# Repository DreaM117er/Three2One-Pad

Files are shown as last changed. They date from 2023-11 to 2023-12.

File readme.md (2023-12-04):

# Three2One Pad

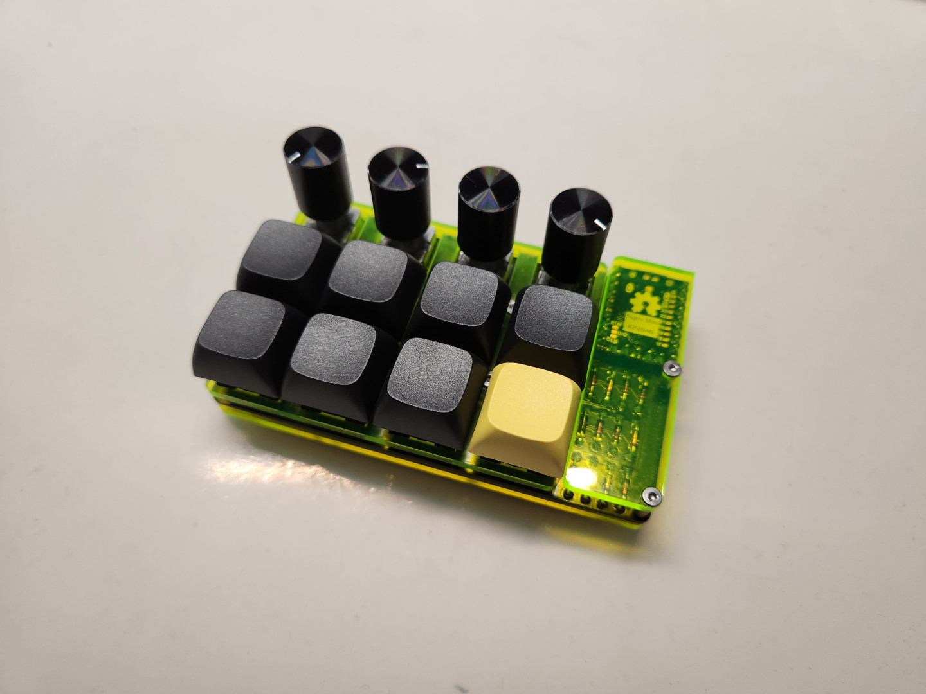
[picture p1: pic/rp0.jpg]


## Description

### What is 321 Pad?

Three2One Pad is a small keyboard pad for persional function keys. It supported maxium 12 keyboard keys or 8 keyboard keys + 4 rotray encoder, MX switches hotswap, and used RP2040 mini series micro controller (ex. supermini/zero... etc) to drive.

This is a simple repostiory, it would be opensource all files on here, check files inside floder.

### Layout and Keymap

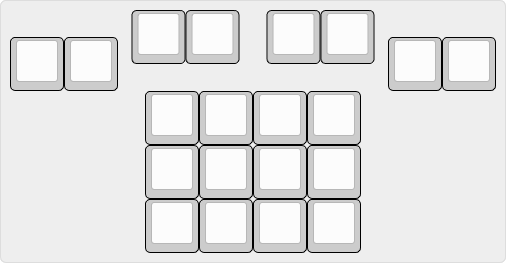
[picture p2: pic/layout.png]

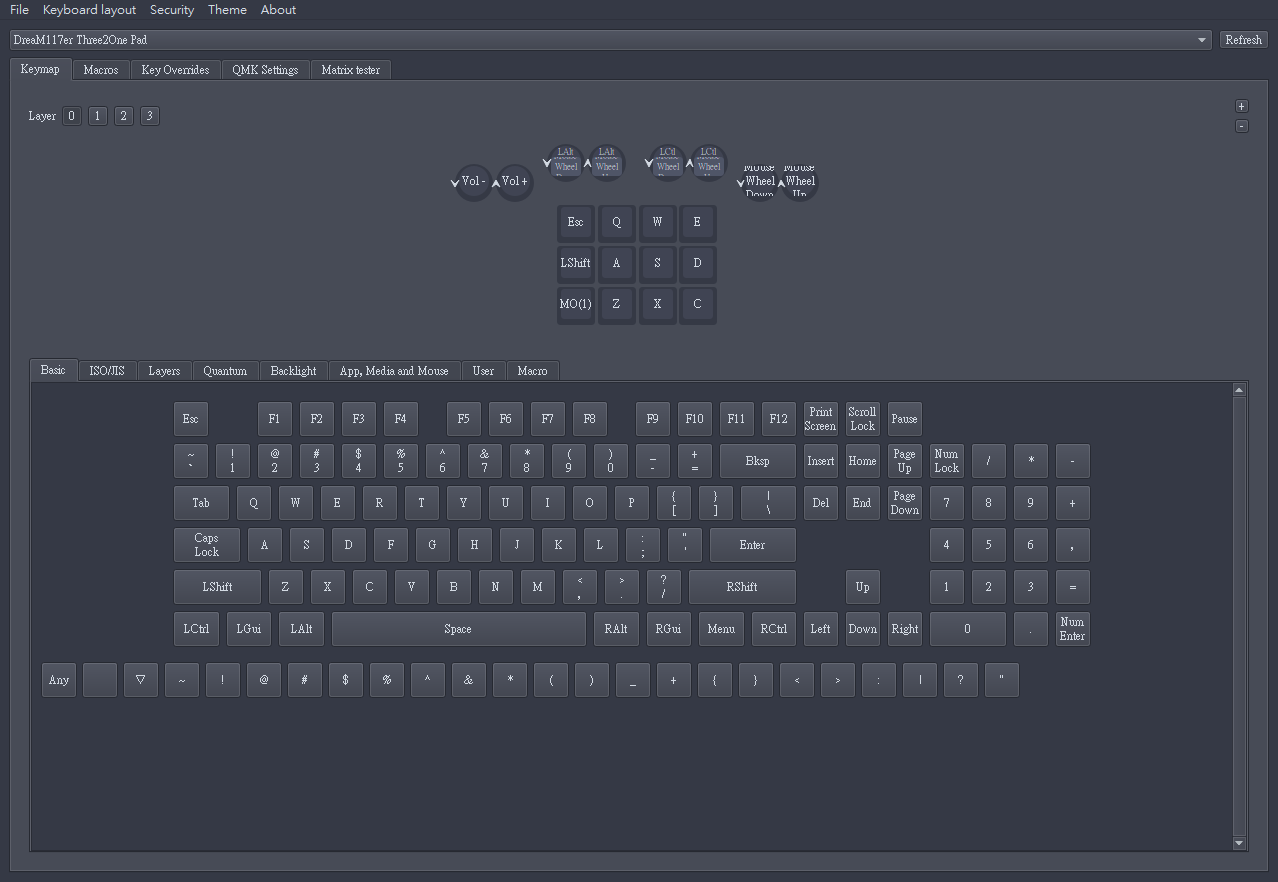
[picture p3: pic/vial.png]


## PCB & 3D module

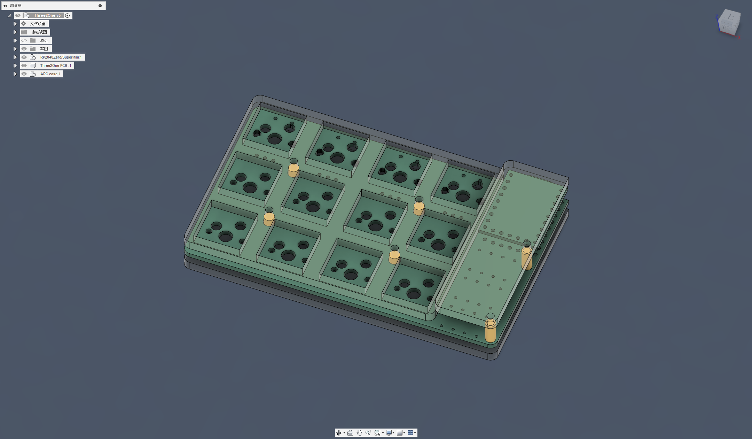
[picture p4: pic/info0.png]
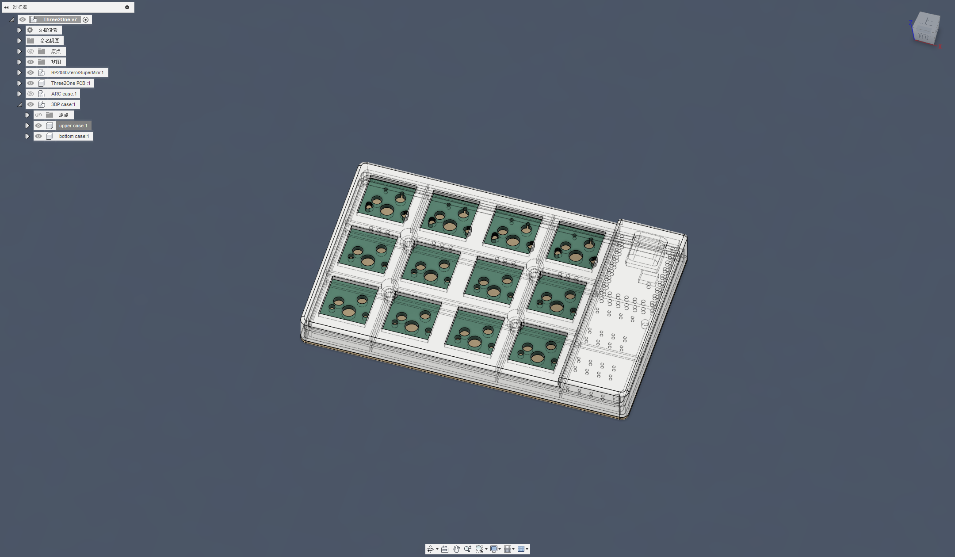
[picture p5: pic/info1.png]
|||
|---|---|
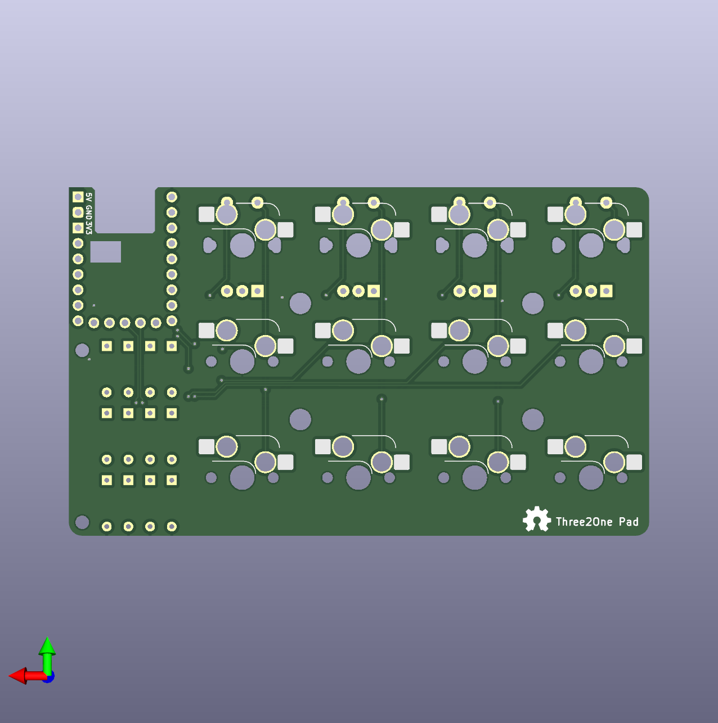
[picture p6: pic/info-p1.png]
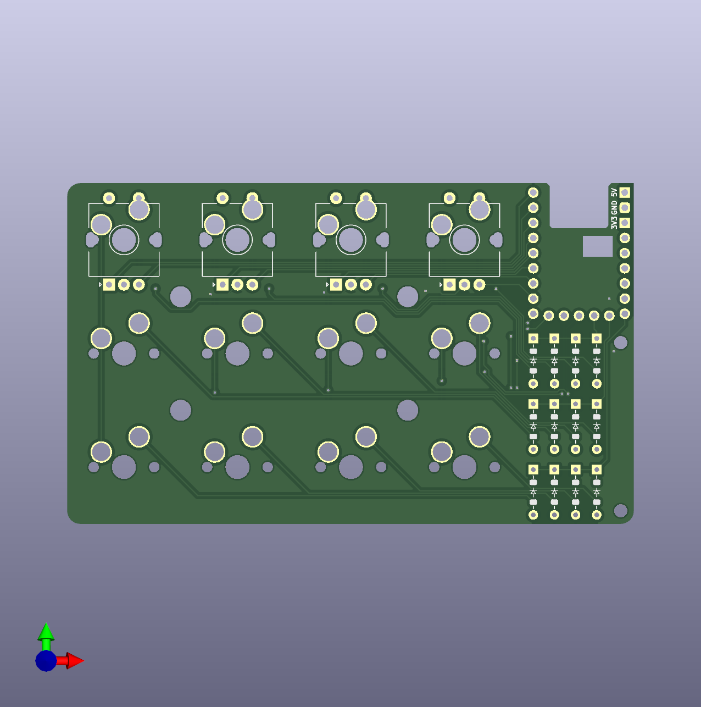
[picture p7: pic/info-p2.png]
|||

## Building Guide

### Material

|Item|Amount|Note|
|---|---|---|
|PCB|1|-|
|MCU|1|RP2040 `SuperMini`/`Zero`|
|Cases|1|`Acrylic` or `3DP`|
|Hotswap Socket|8-12|`MX` version|
|Diodes `1N4148`|12|`SOD-123` or `DO-35` version|
|`M2x5mm` Screw|12|for `Arcylic case`|
|`M2x6mm` Spacer|6|for `Arcylic case`|
|Rotray Encoder `EC-11`|0-4|`Personal Option`|
|Rubber feets|4|`ø8mm`, `H1mm`|

### Guide.1: PCB part

- Prepare hotswap sockets and solder gun, you need to install them first.

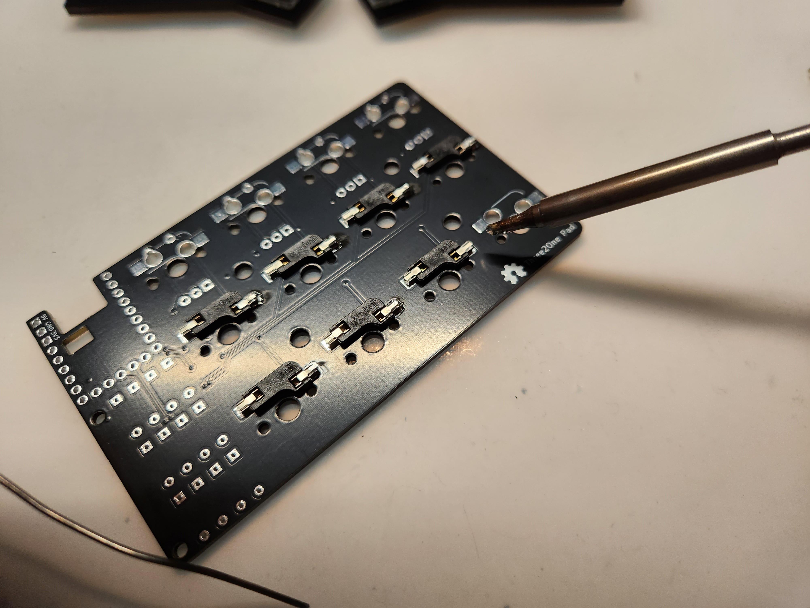
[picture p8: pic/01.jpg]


- Then install diodes to PCB.

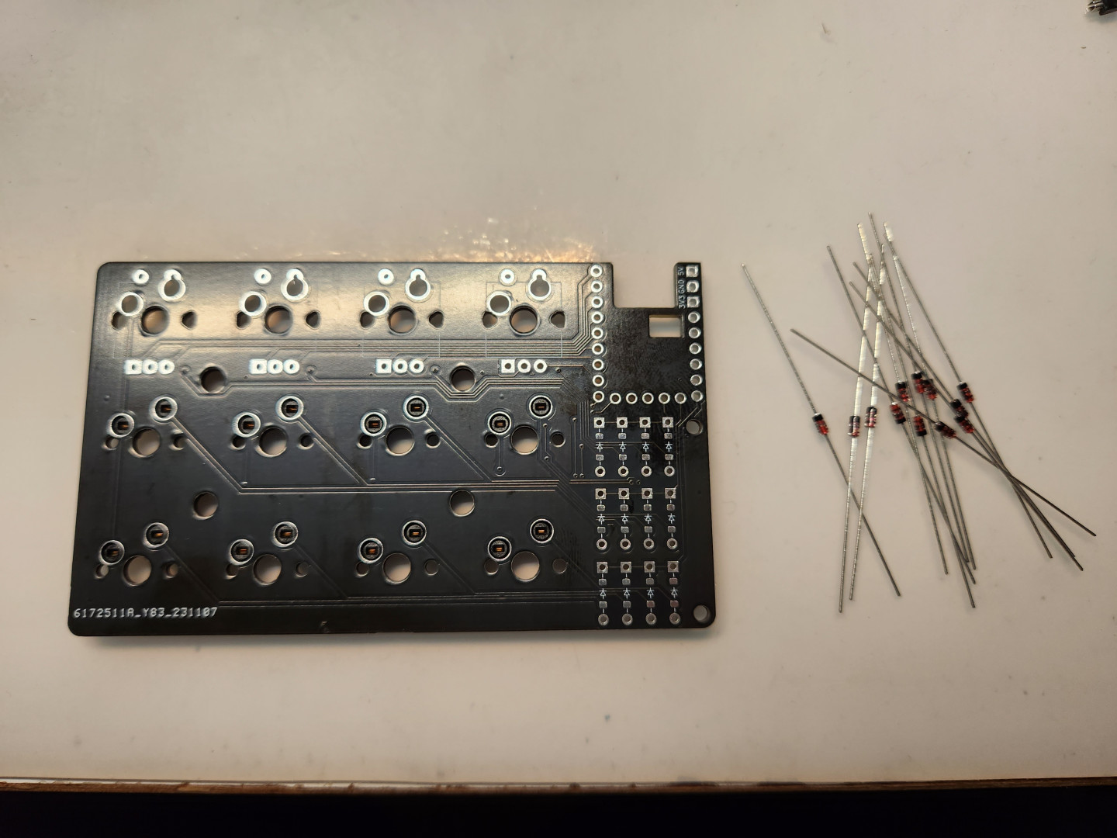
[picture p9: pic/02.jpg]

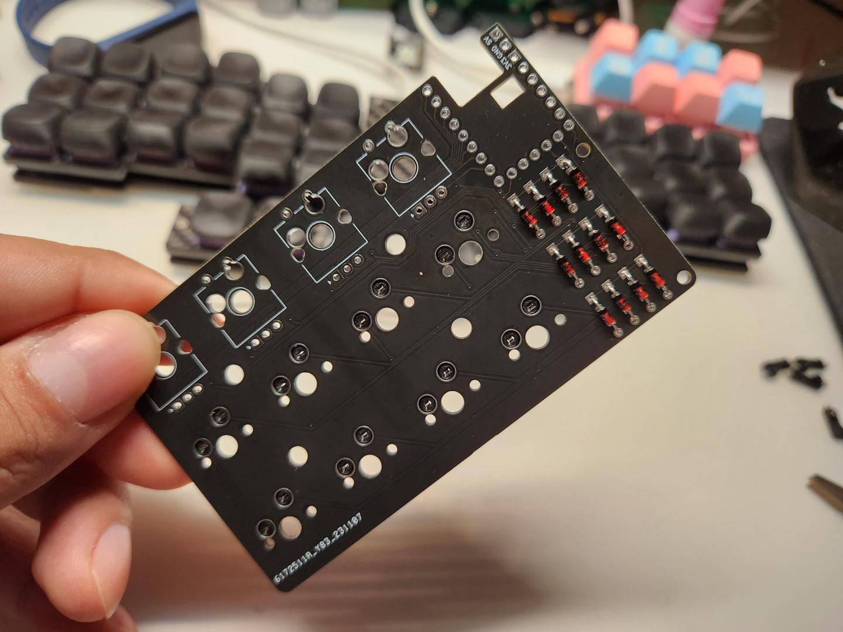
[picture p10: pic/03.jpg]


- Cut off useless diode feets after solder 1N4148 diodes.

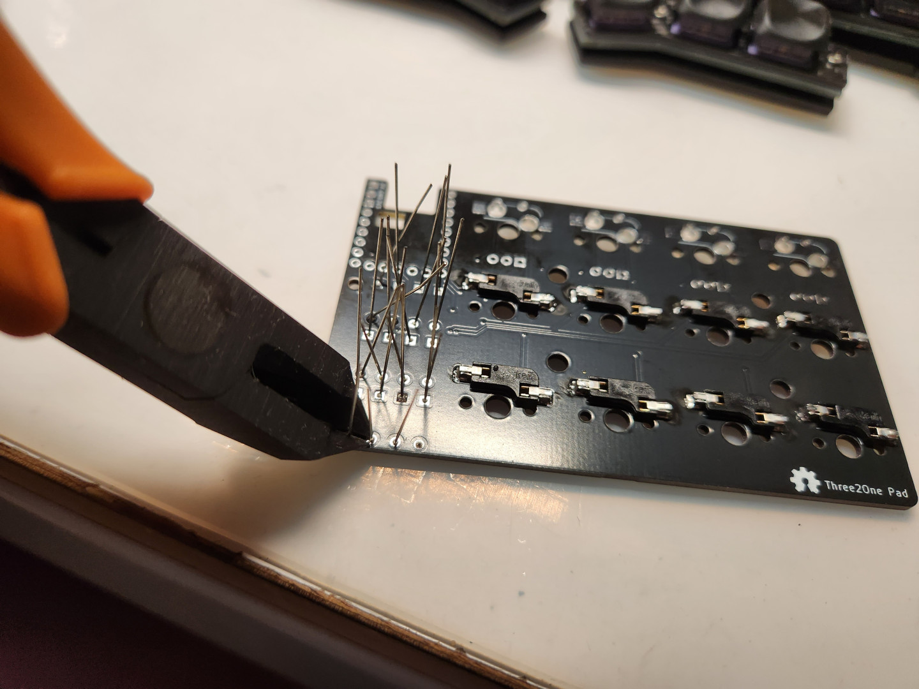
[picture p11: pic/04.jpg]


- If you finished solder diodes, next way is install MCU.

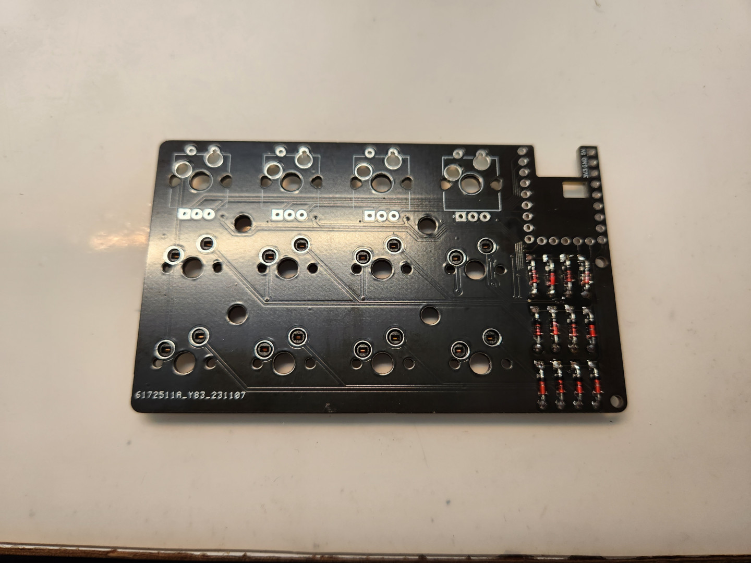
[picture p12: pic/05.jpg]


- Install pin header to PCB then put MCU on top of headers.

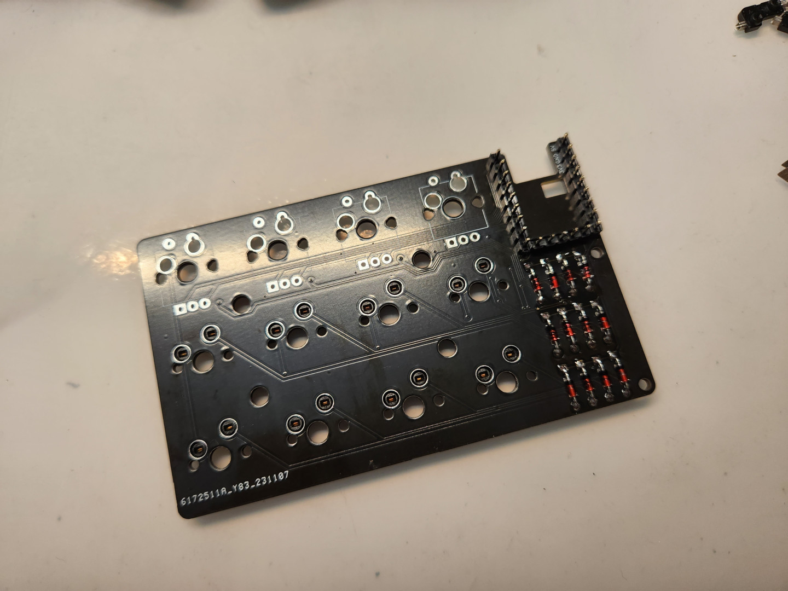
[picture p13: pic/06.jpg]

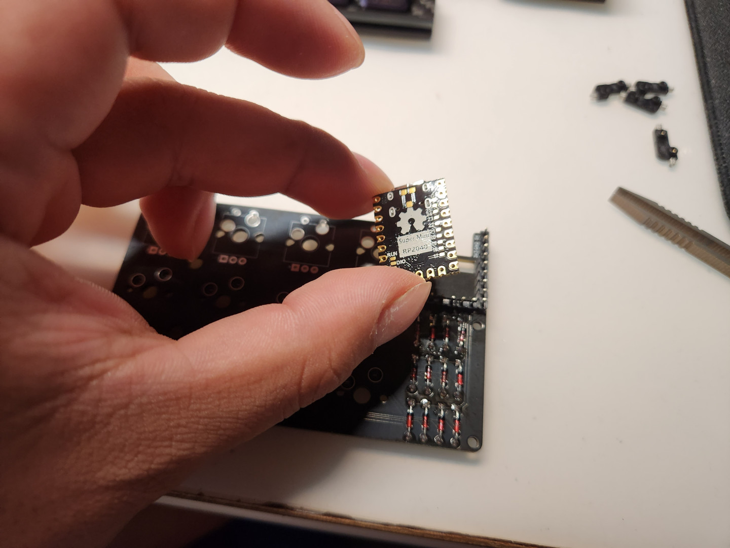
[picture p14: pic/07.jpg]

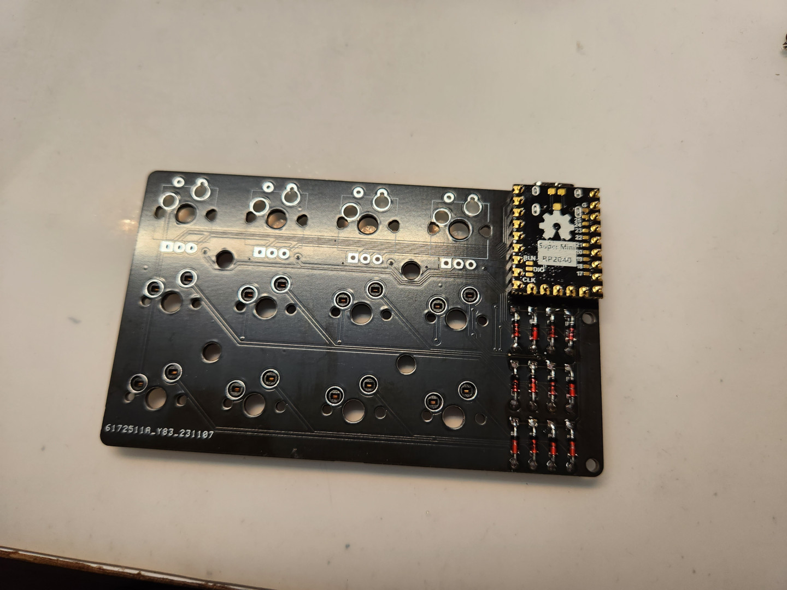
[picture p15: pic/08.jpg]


- Rotray Encoders are persional option. If you want to install them, please decide to install 0-4 EC-11(s) on the PCB.

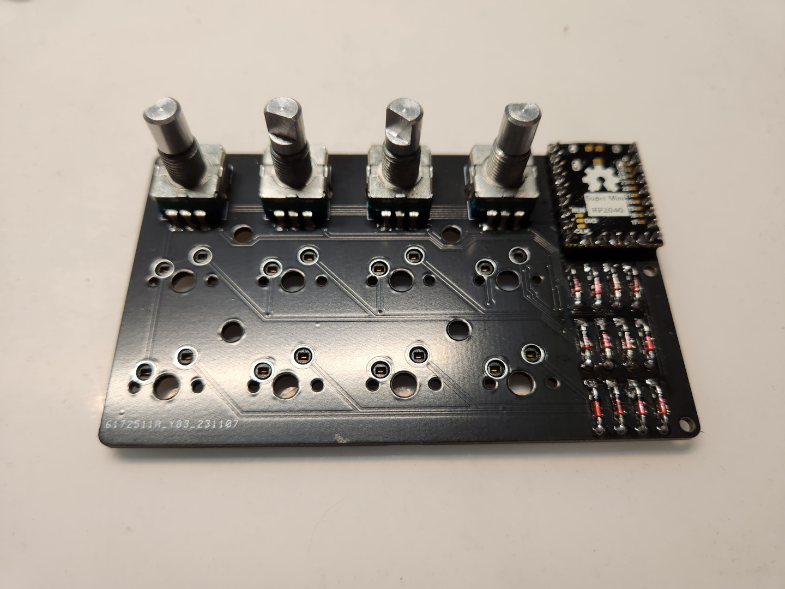
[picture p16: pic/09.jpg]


- Last step flash firmware and test how's the pad working.

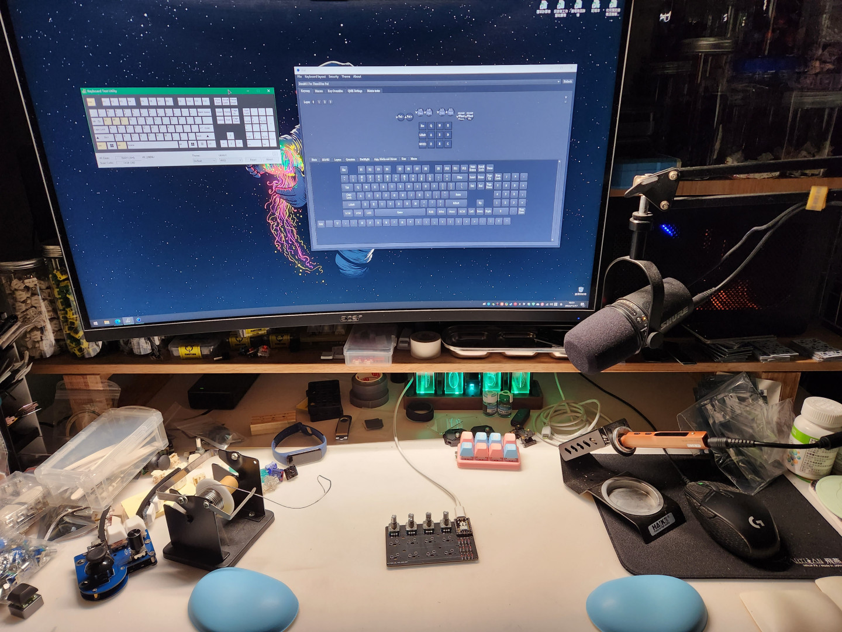
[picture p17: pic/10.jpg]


> **Note**
>
> RP2040 SuperMini/Zero have same `bootloader` way, you need to keep pushing switch on the MCU `before` plug USB-C cable to the PC. After that, you can see a `disk` on your device, then put `.uf2` firmware file into disk.

### Guide.2: Case part

- First install spacers on PCB and bottom case.

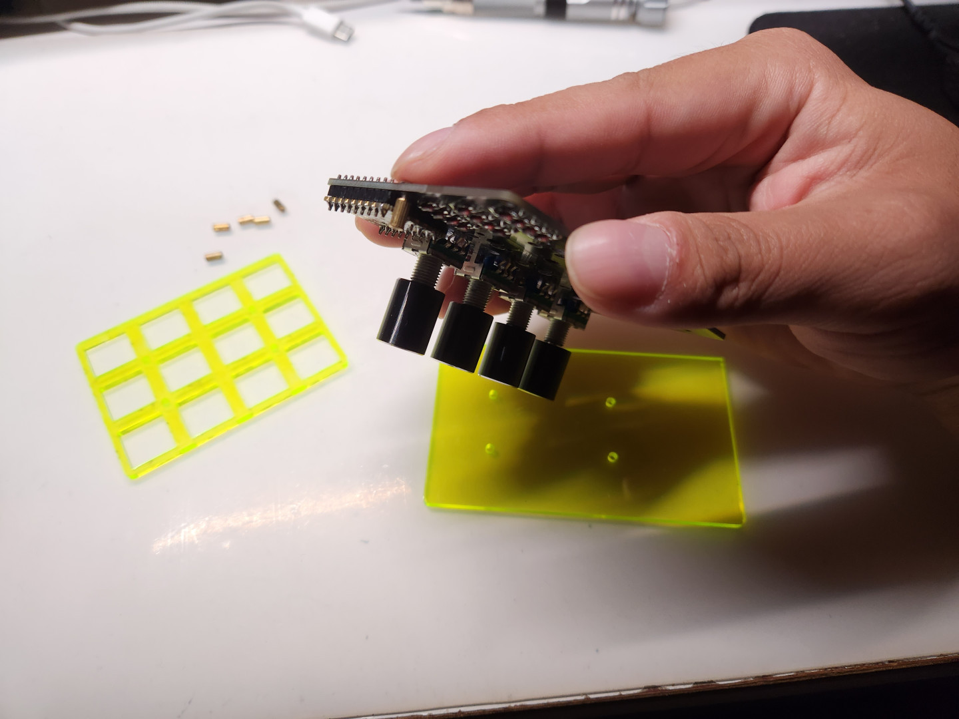
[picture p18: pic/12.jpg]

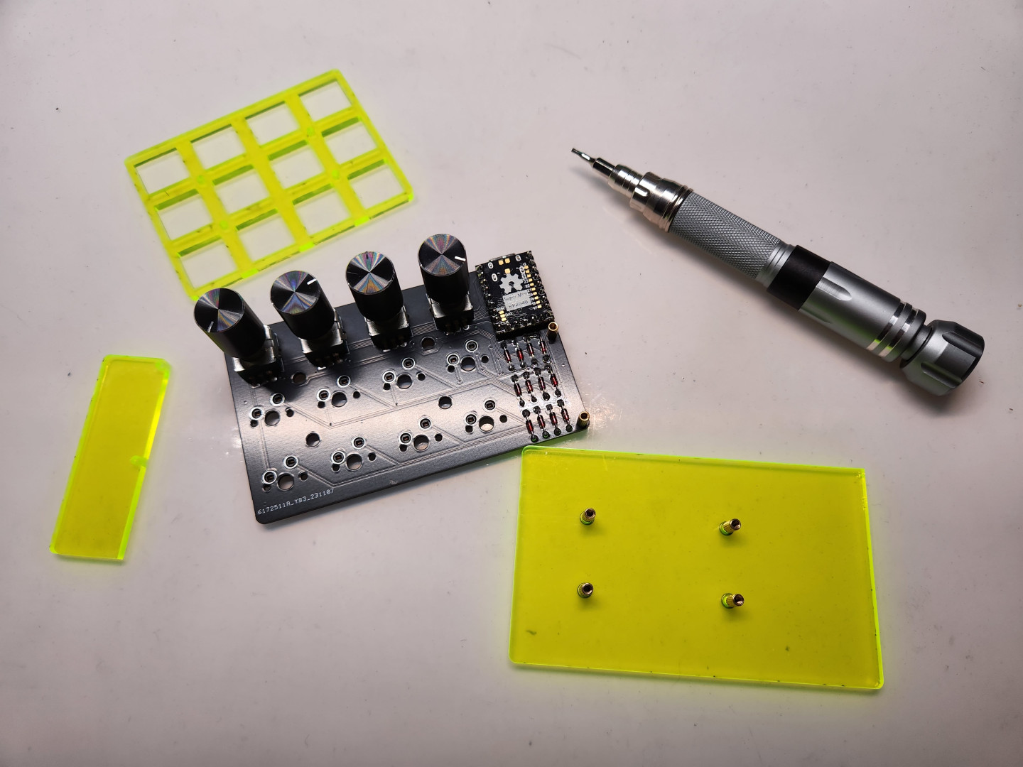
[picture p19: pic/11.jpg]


- Put the PCB on bottom case, then install plate and cover.

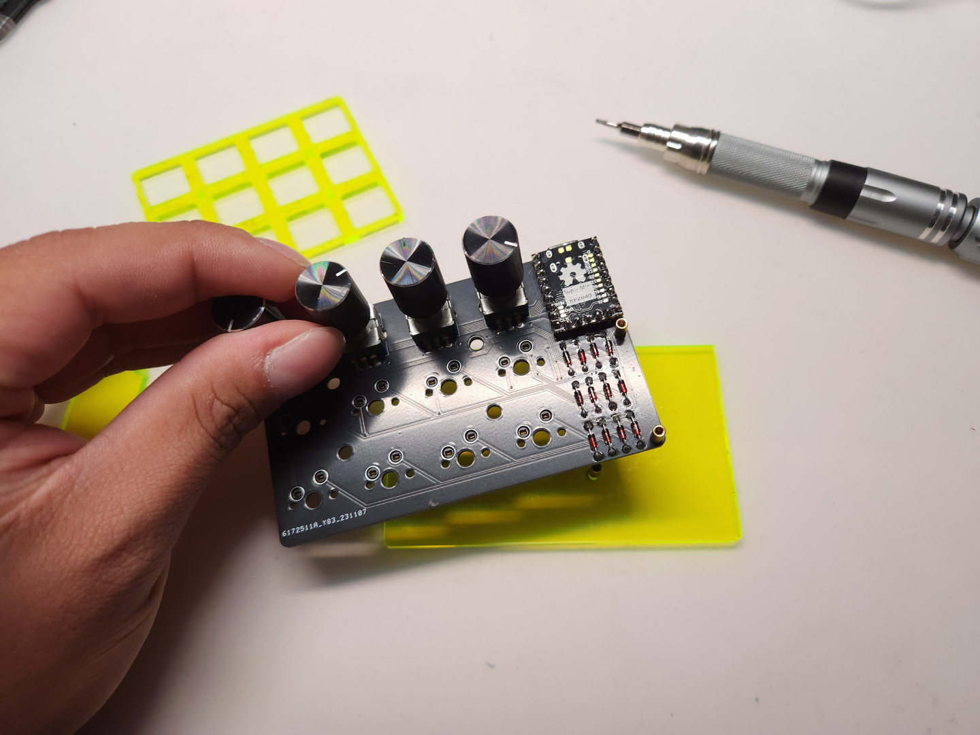
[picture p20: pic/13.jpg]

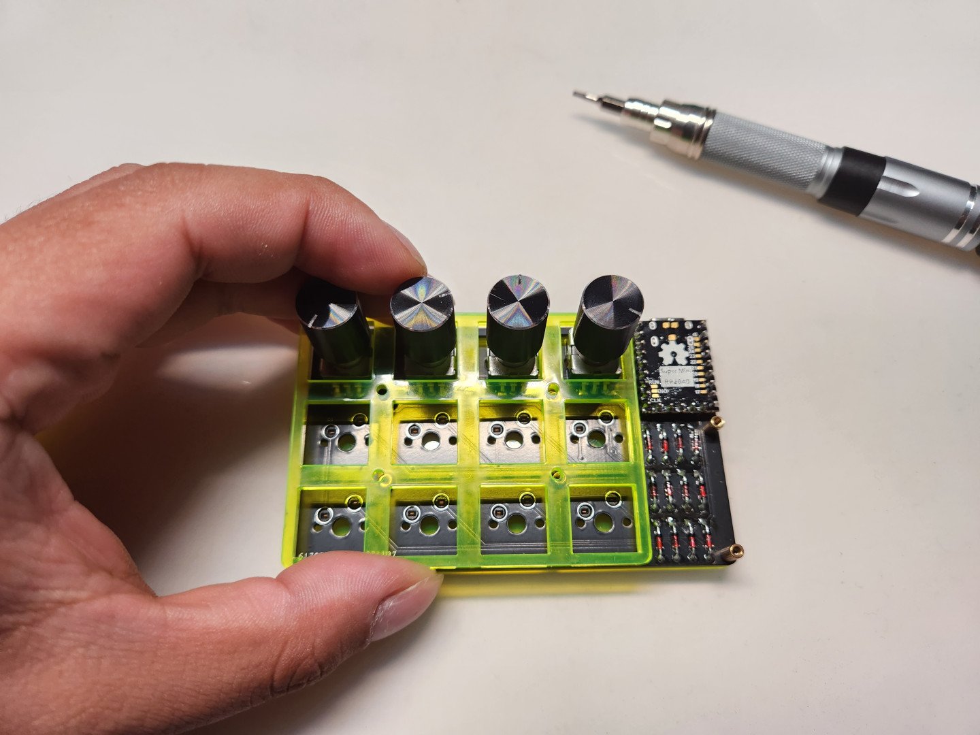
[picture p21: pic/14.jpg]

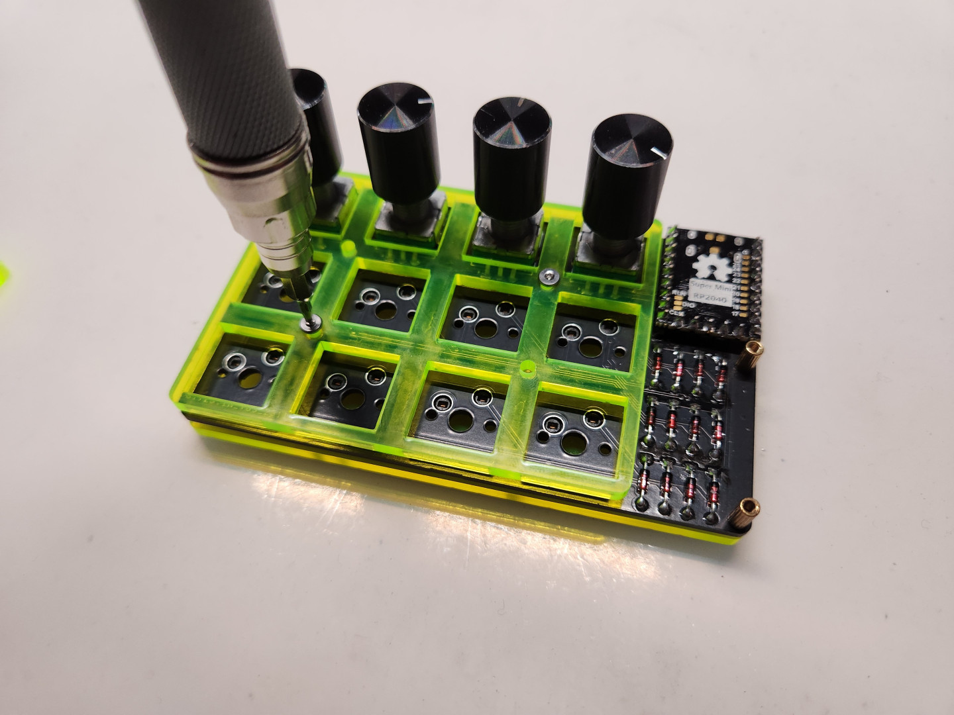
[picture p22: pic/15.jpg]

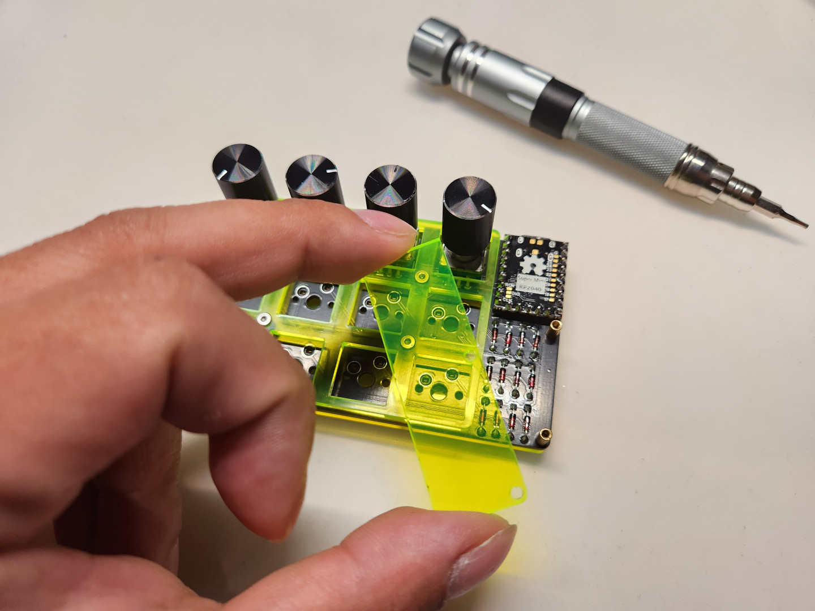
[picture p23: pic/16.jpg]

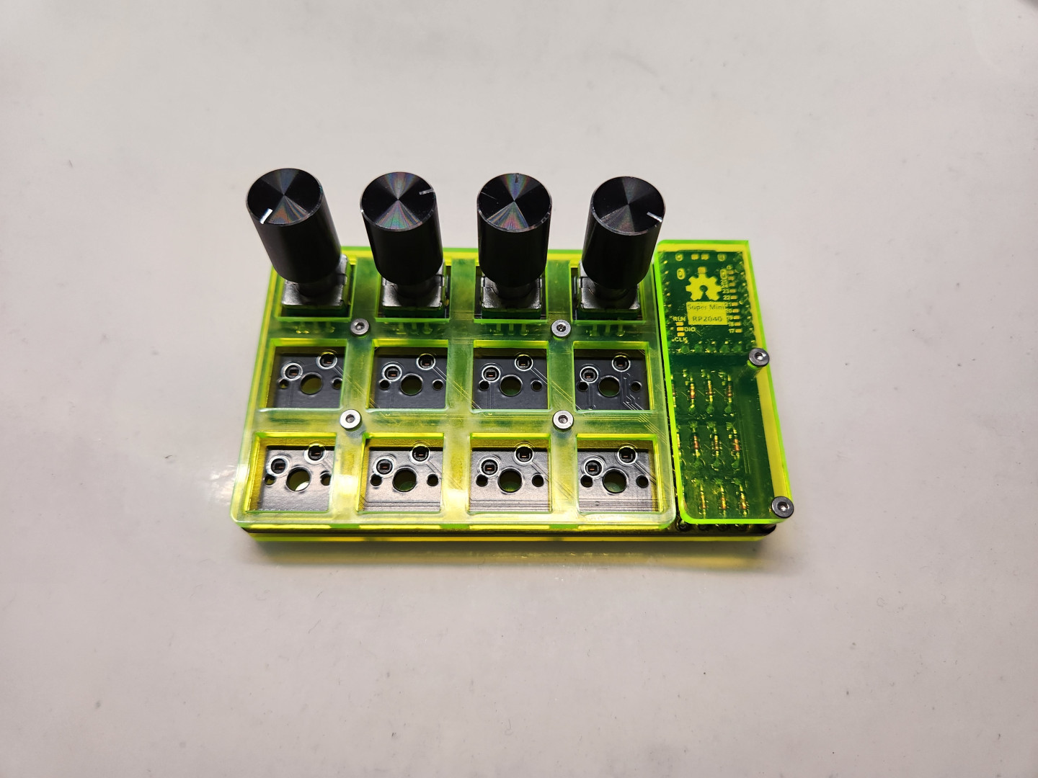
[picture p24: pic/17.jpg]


- If you finish case installed, put 4 rubber feets below the bottom case.

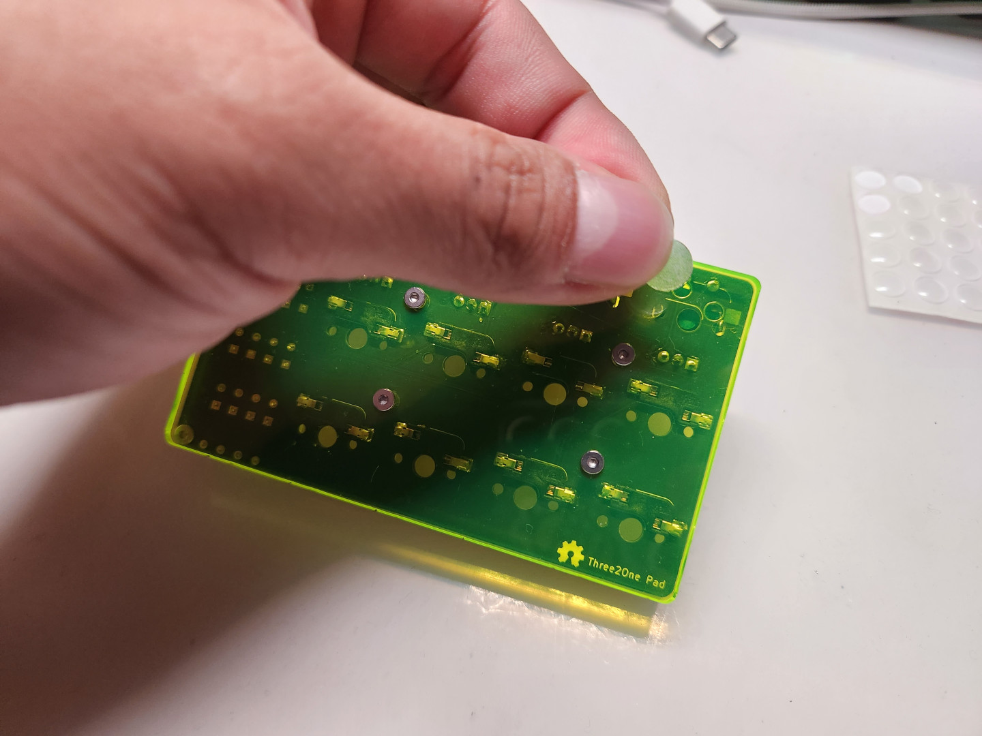
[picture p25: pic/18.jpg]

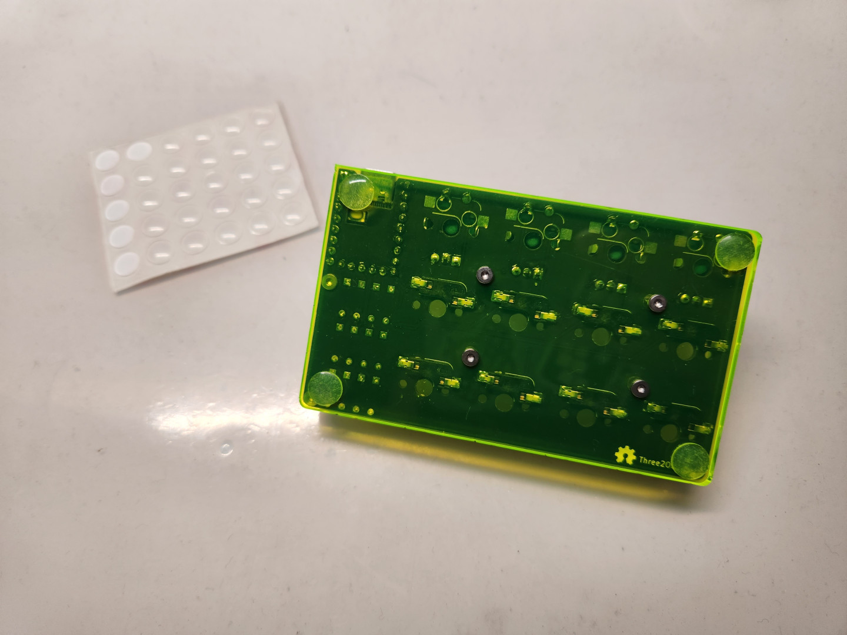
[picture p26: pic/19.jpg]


- Last step, put MX switches and keycaps on the pad.

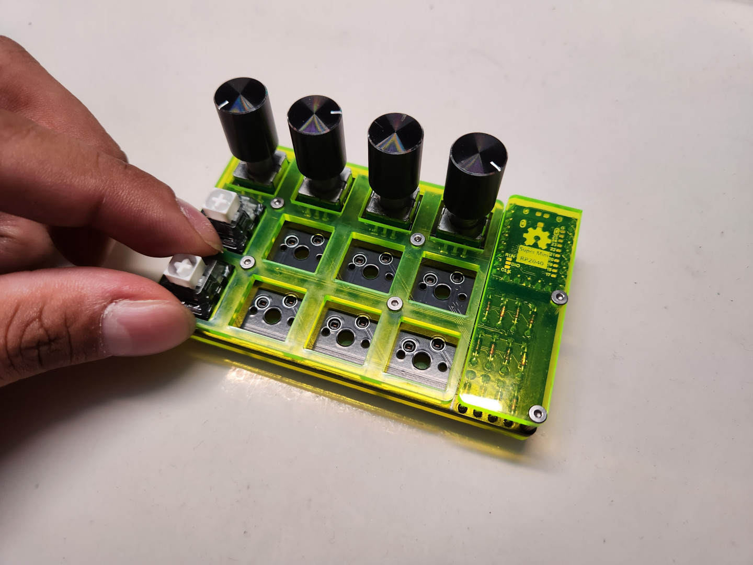
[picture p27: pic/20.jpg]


- Done.



## Informations and Special Thanks

- [QMK Firmware](https://qmk.fm/).
- [VIAL](https://get.vial.today/).
- [KiCAD](https://www.kicad.org/) version `7.0.5.`
- [JLCPCB](https://jlcpcb.com/).
- [AutoDesk Fusion360](https://www.autodesk.com/products/fusion-360/free-trial).
- Taiwan [Tatung University](https://www.ttu.edu.tw/) - [Department of Mechanical and Materials Engineering](https://mme.ttu.edu.tw/)
- And my friend: [YCT](https://github.com/yct38)

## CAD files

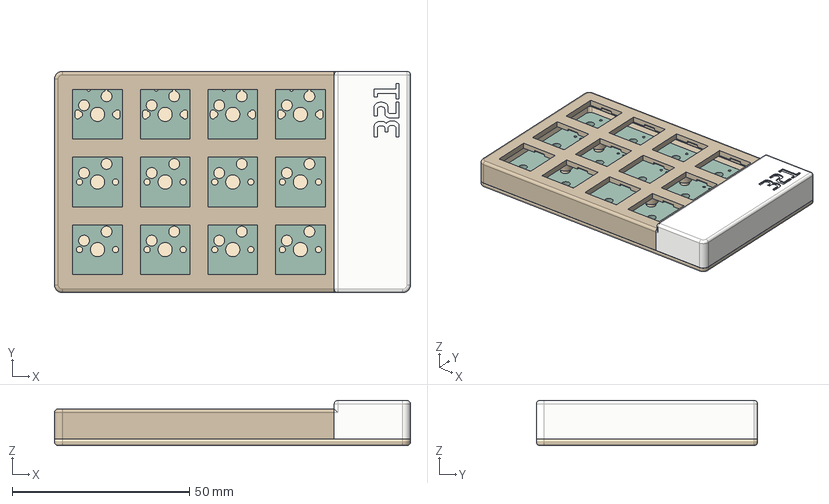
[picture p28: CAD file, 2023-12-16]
file/3Dmodule/3DP version.step
100.3 x 62.3 x 12.7 mm
MCU
Three2One PCB
upper case
bottom case
plate case

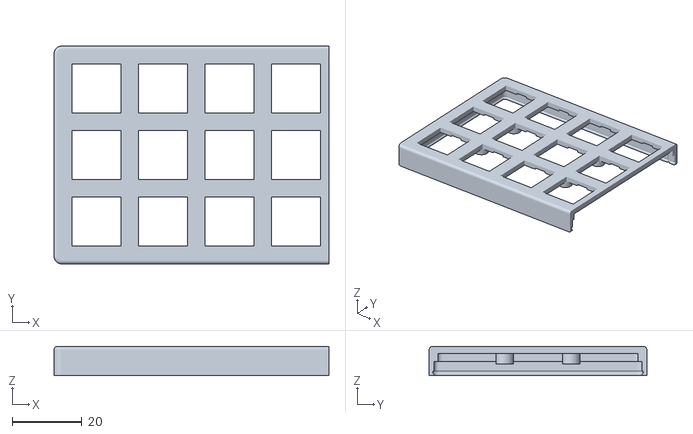
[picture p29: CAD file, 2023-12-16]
file/case/3DP/plate case.stl
78.7 x 62.3 x 8.40

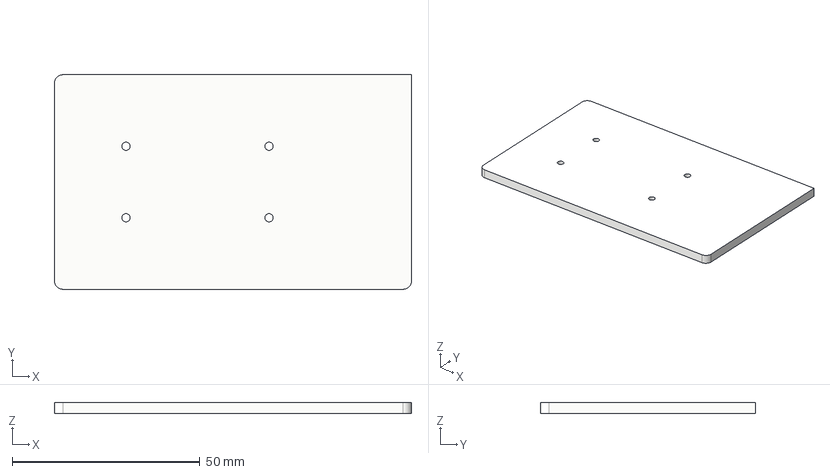
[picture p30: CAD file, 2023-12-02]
file/case/ARC/Bottom.step
95.1 x 57.1 x 3.00 mm

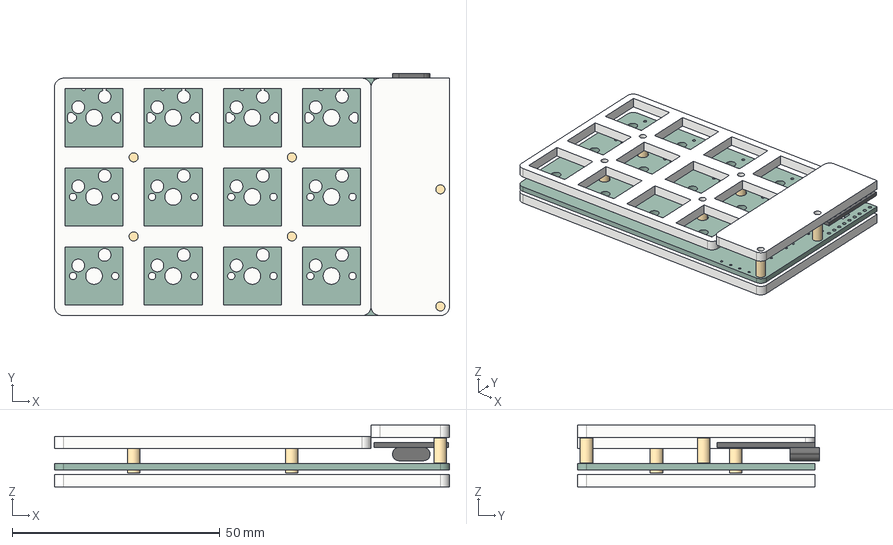
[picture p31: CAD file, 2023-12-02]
file/3Dmodule/ARC version.step
95.1 x 58.3 x 14.9 mm
MCU
Three2One PCB
Plate
Cover
Bottom
6mm spacer mcu x 2
6mm spacer x 4

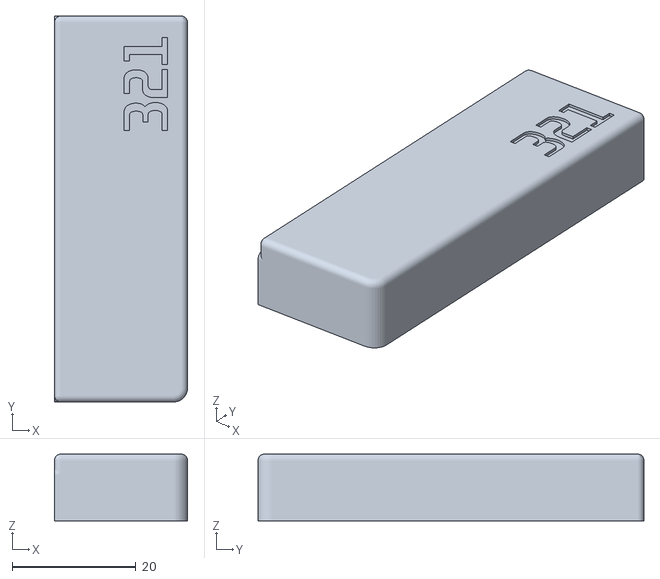
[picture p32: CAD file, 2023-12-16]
file/case/3DP/upper case.stl
21.5 x 62.3 x 10.8

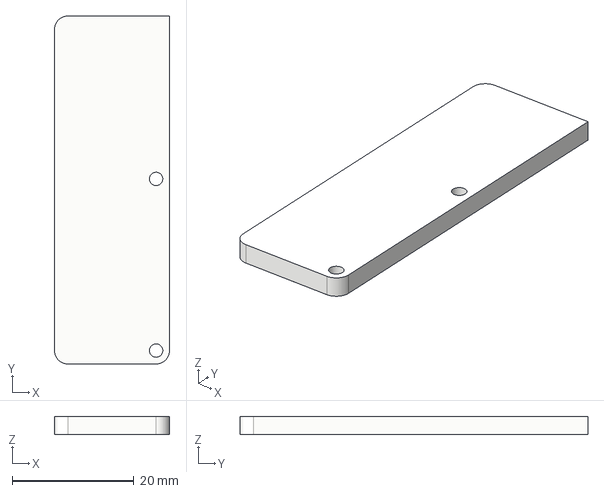
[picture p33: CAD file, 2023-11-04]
file/case/ARC/Cover.step
18.9 x 57.1 x 3.00 mm

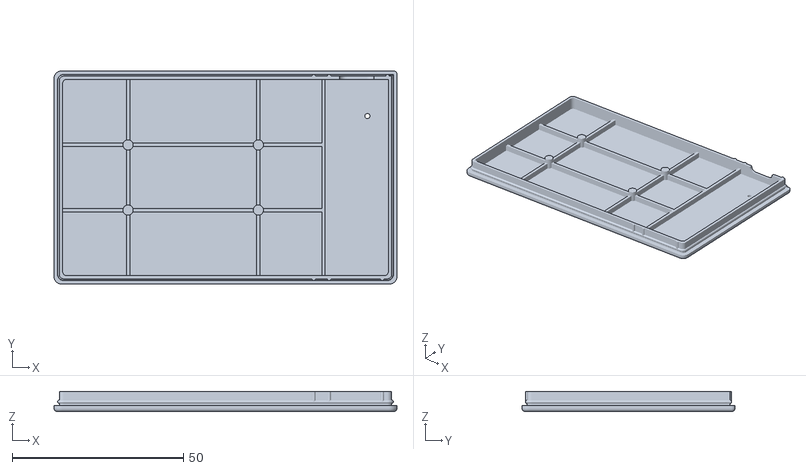
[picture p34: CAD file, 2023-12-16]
file/case/3DP/bottom case.stl
100.3 x 62.3 x 5.90

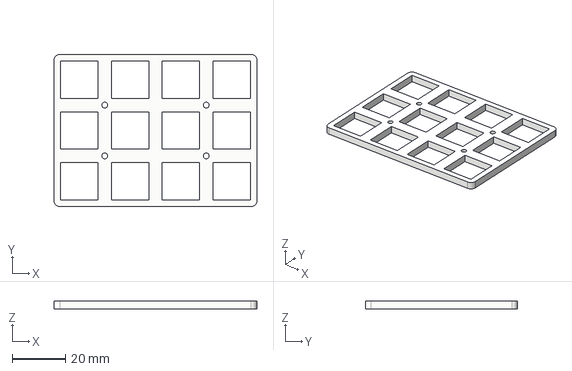
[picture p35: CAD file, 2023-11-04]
file/case/ARC/Plate.step
76.2 x 57.1 x 3.00 mm

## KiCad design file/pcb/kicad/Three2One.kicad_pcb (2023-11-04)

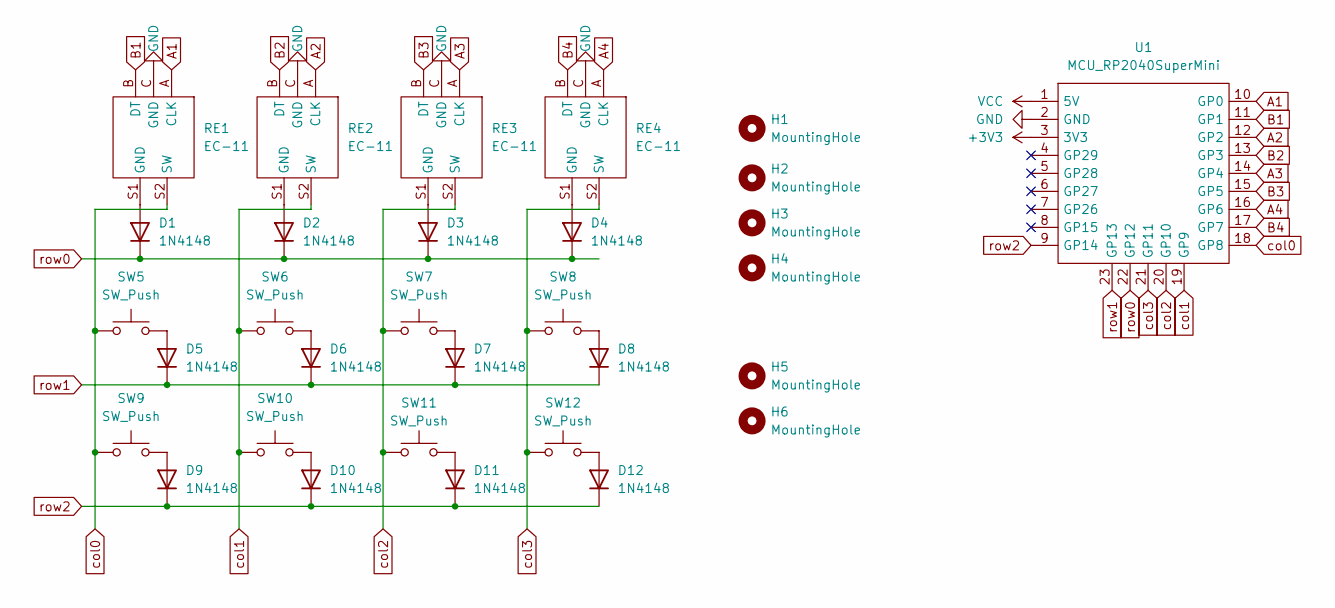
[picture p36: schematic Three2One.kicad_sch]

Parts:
D1, D2, D3, D4, D5, D6, D7, D8, D9, D10, D11, D12: 1N4148; D_DO-35_SOD27_P7.62mm_Horizontal
H1, H2, H3, H4: MountingHole; MountingHole_3.5mm
H5, H6: MountingHole; MountingHole_2.2mm_M2
RE1, RE2, RE3, RE4: EC-11; SW_Hotswap_Kailh_MX_Plated_1.00u_withEC-11
SW5, SW6, SW7, SW8, SW9, SW10, SW11, SW12: SW_Push; SW_Hotswap_Kailh_MX_Plated_1.00u
U1: MCU_RP2040SuperMini

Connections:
+3V3: U1.3 (3V3)
A1: RE1.A (CLK), U1.10 (GP0)
A2: RE2.A (CLK), U1.12 (GP2)
A3: RE3.A (CLK), U1.14 (GP4)
A4: RE4.A (CLK), U1.16 (GP6)
B1: RE1.B (DT), U1.11 (GP1)
B2: RE2.B (DT), U1.13 (GP3)
B3: RE3.B (DT), U1.15 (GP5)
B4: RE4.B (DT), U1.17 (GP7)
GND: RE1.C (GND), RE2.C (GND), RE3.C (GND), RE4.C (GND), U1.2 (GND)
unnamed: D1.2 (A), RE1.S1 (GND)
unnamed: D2.2 (A), RE2.S1 (GND)
unnamed: D3.2 (A), RE3.S1 (GND)
unnamed: D4.2 (A), RE4.S1 (GND)
unnamed: D5.2 (A), SW5.2
unnamed: D6.2 (A), SW6.2
unnamed: D7.2 (A), SW7.2
unnamed: D8.2 (A), SW8.2
unnamed: D9.2 (A), SW9.2
unnamed: D10.2 (A), SW10.2
unnamed: D11.2 (A), SW11.2
unnamed: D12.2 (A), SW12.2
VCC: U1.1 (5V)
col0: RE1.S2 (SW), SW5.1, SW9.1, U1.18 (GP8)
col1: RE2.S2 (SW), SW6.1, SW10.1, U1.19 (GP9)
col2: RE3.S2 (SW), SW7.1, SW11.1, U1.20 (GP10)
col3: RE4.S2 (SW), SW8.1, SW12.1, U1.21 (GP11)
row0: D1.1 (K), D2.1 (K), D3.1 (K), D4.1 (K), U1.22 (GP12)
row1: D5.1 (K), D6.1 (K), D7.1 (K), D8.1 (K), U1.23 (GP13)
row2: D9.1 (K), D10.1 (K), D11.1 (K), D12.1 (K), U1.9 (GP14)

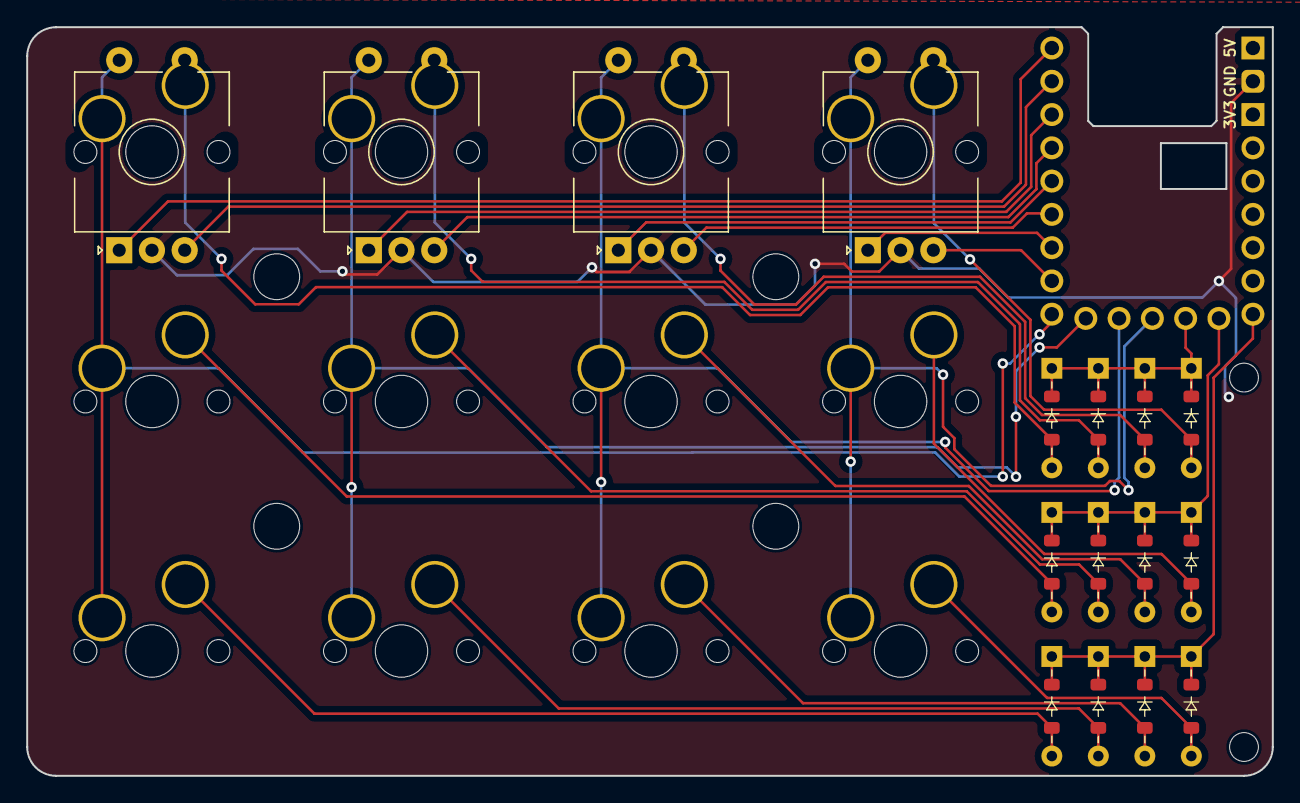
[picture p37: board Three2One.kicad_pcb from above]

Board: 2 copper layers, 95.1 x 57.1 mm, 31 parts (1 on the bottom side), 28 nets.

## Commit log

2023-11-04 update readme.md & files
    [ARC version.step, Bottom.step, Cover.step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]
2023-11-11 update 3DP case
    [3DP version.step, ARC version.step, bottom case.stl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]
2023-12-02 fix arc case
    [ARC version.step, Bottom.step]
2023-12-11 fix 3DP case and module
    [3DP version.step, bottom case.stl, plate case.stl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]
2023-12-15 fix 3DP case plate
    [3DP version.step, plate case.stl]
2023-12-16 fix 3DP case
    [3DP version.step, bottom case.stl, plate case.stl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]
